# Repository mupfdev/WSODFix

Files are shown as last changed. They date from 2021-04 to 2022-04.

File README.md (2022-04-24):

# WSODFix

<p>
<a href="https://github.com/mupfelofen-de/WSODFix">
    
</a>
<a href="https://github.com/mupfelofen-de/WSODFix/blob/master/LICENSE.md">
    
</a>
<a href="https://www.travis-ci.com/mupfelofen-de/WSODFix">
    
</a>
</p>

## About

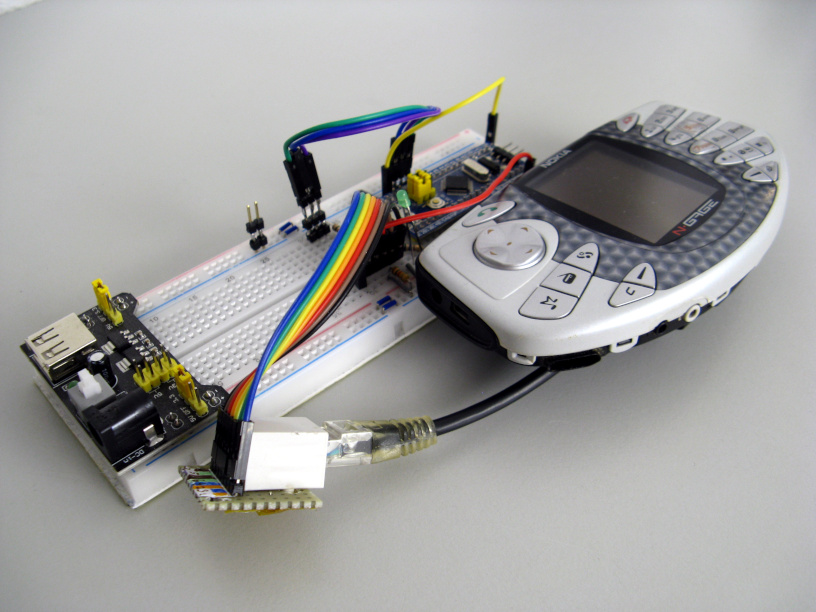
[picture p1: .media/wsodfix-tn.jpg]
WSODFix


Nokia mobile phones such as the N-Gage running early versions of the
Symbian OS suffer from a very common problem widely known as the White
Screen of Death or simply WSOD.  This happens when the internal memory
of the phone becomes so full that the unit can no longer boot and
becomes virtually unusable.

To solve this, the memory, referred to here as the user area, must be
formatted.

However, professional flashing equipment is needed to achieve this and
nowadays it is hard to find such equipment for sale.  More than often,
manufacturers, which cloned official service hardware, sold it in
addition to hardware licences in the form of a dongle.  Also, as new
devices would come out, old ones would literally be rendered unusable by
the manufacturers via the internet or sometimes by malware-infected
software released by competitors.

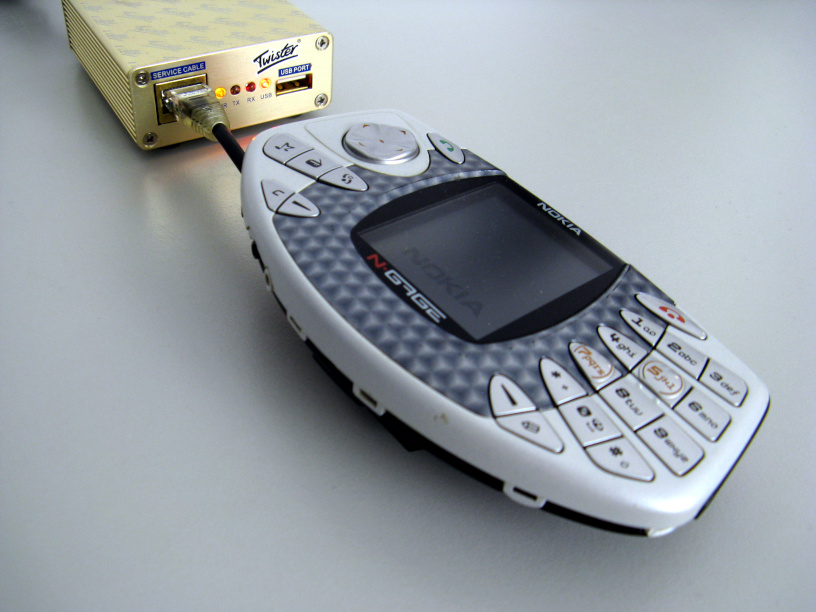
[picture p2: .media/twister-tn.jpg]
Twister


There is official software with which some of these devices can be
repaired and reactivated with, but access to reliable information is
anything but trivial.

This project is not an alternative to professional flashing equipment,
but aims at offering the possibility to make older Symbian phones
affected by a simple WSOD usable again by leveraging open-source
software and DIY hardware.

The project is based on a STM32F103C8 microcontroller board a.k.a. a
[blue pill board](http://reblag.dk/stm32/).

## Status

### Firmware

The firmware is 100% functional.

### Compatible phones

WSODFix has been tested with the following phones so far:

- Nokia N-Gage (NEM-4)
- Nokia N-Gage QD (RH-29)

## Operating instructions

Important: Never use WSODFix with a working phone! If the formatting
fails or is interrupted in the process, the device may no longer
boot. This can then only be repaired by a successful run.

1. Connect the UFS flashing cable to your phone.  It is very important
   to follow the correct insertion and removal procedure, otherwise the
   contact pins on the flash adapter will be damaged.  For the N-Gage
   and N-Gage QD, you must first press the adapter against the battery
   contacts and then down.

2. Attach the cable to the RJ45 connector of your WSODFix.

3. Connect the USB cable. Make sure that the USB port used can supply
   sufficient power for the phone and the microcontroller.

4. First, the LED should flash for about 20 seconds at a rate of 1
   second.  This is when the phone enters service mode.

5. Wait until the formatting process begins. The LED then flashes at a
   rate of 30ms.

6. The process is completed when the LED lights up continuously. You can
   then disconnect the phone and try to turn it on.  If the procedure
   fails, try again from the beginning.

## Hardware

### Parts needed

- UFS flashing cable or any way to connect the microcontroller to the
  corresponding pins on the phone (for example see the [N-Gage cable
  schematics](docs/Nokia_N-Gage_cable.pdf)),
- [STM32 blue pill board](http://reblag.dk/stm32/)
- RJ45 Ethernet jack,
- [RJ45 Breakout](https://www.sparkfun.com/products/716),
- 1× 1kΩ and 1× 10kΩ resistor (optional),
- 1× External status LED + dropping resistor (optional).

### Schematic

Note: The voltage divider is almost certainly optional.  Alternatively,
you can also set Vpp to 3V3.

Schematic

## FBus

The FBus is a bi-directional full-duplex serial type bus running at
115,200 bit/s, 8 data bits, no parity, one stop bit (8N1).

### Message structure

```text
  [      Header     ] [Payload] [xx xx]
  [1E xx xx xx xx xx] [Payload] [ CRC ]

  [ Header ]
  Byte 0 - F-Bus Frame ID
    E1 = Message via F-Bus cable
  Byte 1 - Destination address
  Byte 2 - Source address
    00 = Phone
    10 = Twister
  Byte 3 - Message type / command
    15 = Handshake/Auth ?
    7F = Acknowledge
    58 = Format user area
  Byte 4 - Payload size in bytes (MSB)
  Byte 5 - Payload size in bytes (LSB)

  [ Payload ]
  Byte 6 ... - Payload

  [ CRC ]
  Byte 1 - even checksum byte (all even bytes XORed together)
  Byte 2 - odd checksum byte  (all odd bytes XORed together)
```

### Formatting the user area

Here is a brief summary of the messages exchanged between the flashing
equipment and the Symbian phone when the user area is formatted.

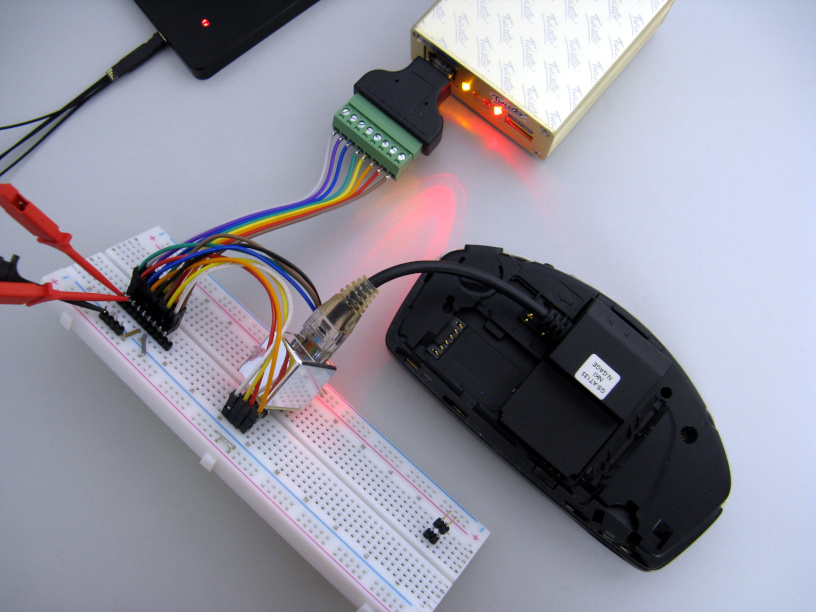
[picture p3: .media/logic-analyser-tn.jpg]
Logic analyser


This description is based on pure observation with the help of a logic
analyser.

```text
SEND 55 55 55 55 55 55 (synchronisation)

ca. 60ms pause

SEND [1E 00 10 15 00 08] [00 06 00 02 00 00 01 60]   [0F 79]
RECV [1E 10 00 7F 00 02] [15 00]                     [0B 6D]
RECV [1E 10 00 15 00 08] [06 27 00 65 05 05 01 (42)] [1C 08]
SEND [1E 00 10 7F 00 02] [15 (02)]                   [1B 7F]

ca. 16ms pause

SEND [1E 00 10 58 00 08] [00 0B 00 07 06 00 01 41]   [09 1D]
RECV [1E 10 00 7F 00 02] [58 01]                     [46 6C]

ca. 40-50s pause

RECV 55 55 (synchronisation)
RECV [1E 10 00 58 00 08] [0B 38 00 08 00 00 01 (43)] [14 33]

SEND [1E 00 10 7F 00 02] [58 (03)]                   [56 7E]
```

Surely you have noticed the parenthesised numbers.  These vary from run
to run.  The Symbian phone sends an initial value between 0x40 and 0x47.
The flashing equipment responds with this number minus 0x40.

Moreover, this number is apparently a kind of frame counter.  For
example, if the phone sends an initial 0x42, the next message sent from
the phone to the flasher will contain the number 0x43.  After 0x47,
there is an overflow back to 0x40.

This frame counter is implemented in WSODFix, but I do not know if it is
mandatory.  The rest of the payload data is completely ignored.  The
firmware only checks the message type of the received FBus messages.  In
my tests, this was 100% reliable.

Unfortunately FBus is a proprietary protocol developed by Nokia.  If you
have detailed specifications that you would like to share with me, I
would greatly appreciate it.  This would also help the further
development of this project.

## Installation

1. Install [PlatformIO Core](http://docs.platformio.org/page/core.html)
2. Run these commands:

```bash
    # Build project
    > platformio run

    # Upload firmware
    > platformio run --target upload

    # Clean build files (optional)
    > platformio run --target clean
```

## Licence

This project is licensed under the "The MIT License".  See the file
[LICENSE.md](LICENSE.md) for details.

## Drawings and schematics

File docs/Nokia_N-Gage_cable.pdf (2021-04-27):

### NOKIA NEM-4 ( N-GAGE ) from Dct4_UFS

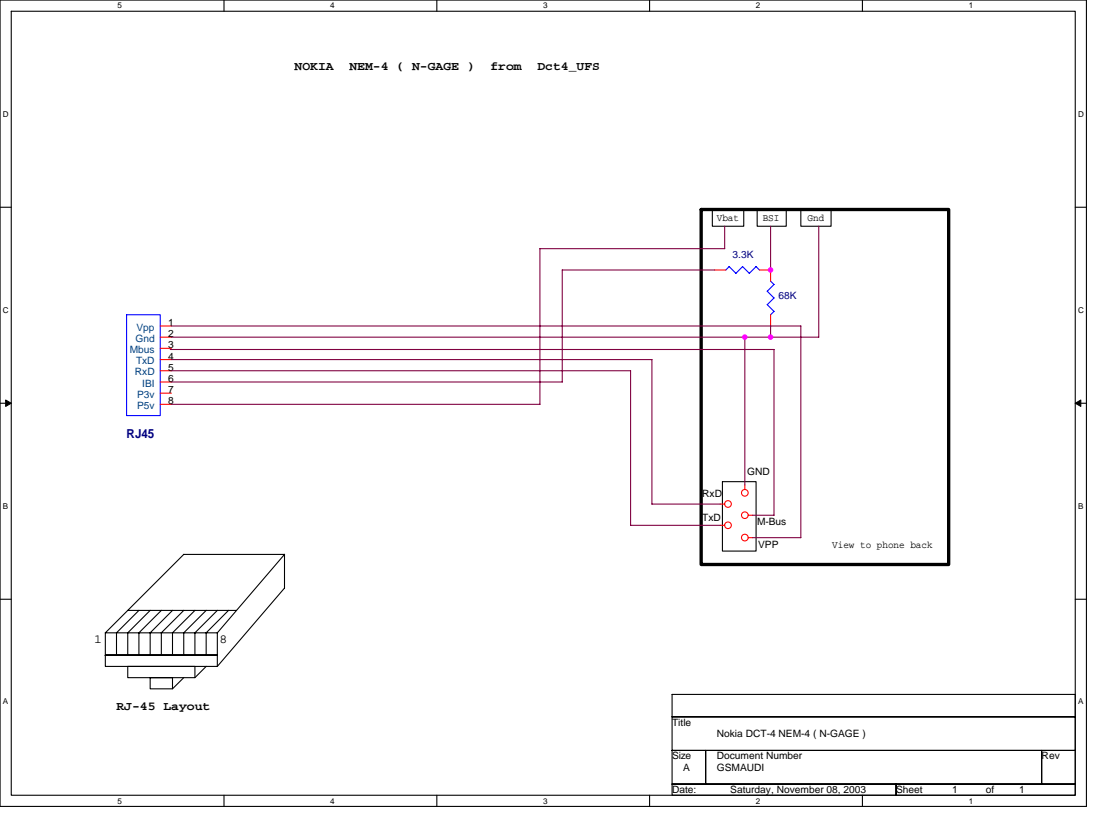
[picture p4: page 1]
Vbat; BSI; Gnd; RJ-45 Layout; Title; VPP; M-Bus TxD; GND; RxD; Vpp Gnd Mbus TxD RxD IBI P3v P5v

View to phone back

Nokia DCT-4 NEM-4 ( N-GAGE )

Size A | Document Number GSMAUDI | Rev

Date: Saturday, November 08, 2003 | Sheet 1 of 1

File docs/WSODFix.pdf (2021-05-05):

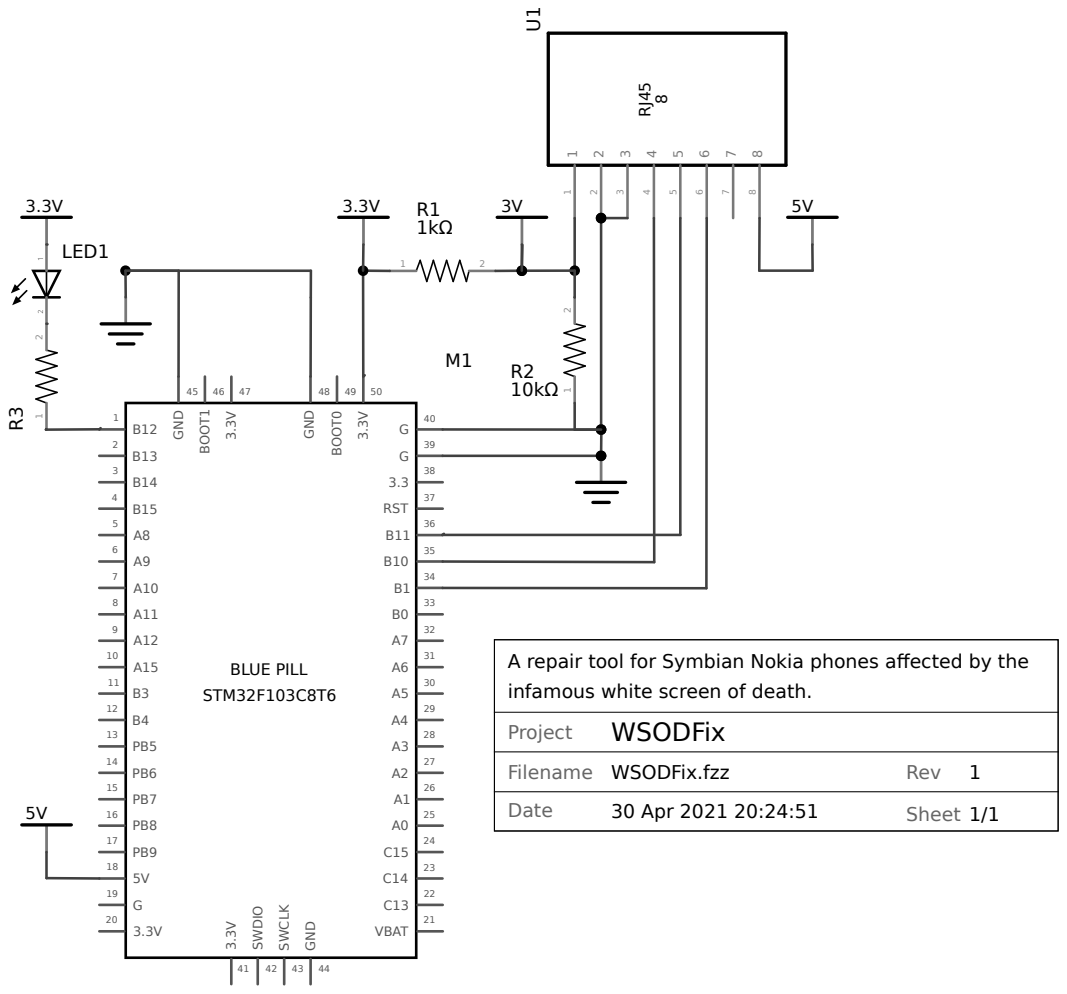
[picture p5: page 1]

A repair tool for Symbian Nokia phones affected by the
infamous white screen of death.

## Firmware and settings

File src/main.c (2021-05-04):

/* Spdx-License-Identifier: MIT */
/**
 * @file main.c
 * @brief WSODFix A repair tool for Symbian Nokia phones affected by the
 *        infamous white screen of death.
 */

#include <stdbool.h>
#include <stdint.h>
#include <string.h>

#include "stm32f1xx_hal.h"
#include "stm32f1xx_hal_tim.h"

#define BUF_SIZE     32
#define FBUS_MSG_LEN 16
#define FBUS_RX_ADDR 0x10
#define FBUS_TX_ADDR 0x00

typedef enum
{
    LED_IDLE               = 500,
    LED_ENTER_SERVICE_MODE = 1000,
    LED_FORMATTING         = 30,
    LED_ALL_DONE           = 0

} led_t;

UART_HandleTypeDef huart3;
TIM_HandleTypeDef  htim2;
TIM_HandleTypeDef  htim4;

static bool    all_done        = false;
static bool    initiate_format = false;
static uint8_t rx_byte         = 0;
static led_t   status_led      = LED_IDLE;
static uint8_t frame_counter   = 0;
static uint8_t tx_buffer[16]   = {
    0x55, 0x55, 0x55, 0x55, 0x55, 0x55,
    0x00, 0x06, 0x00, 0x02, 0x00, 0x00, 0x01, 0x60,
    0x0F, 0x79
};

static void system_init(void);
static void service_mode_init(void);
static void comm_init(void);
static void calculate_crc(uint8_t buffer[16], uint8_t* even_crc, uint8_t* odd_crc, bool append);
static void error_handler(void);

int main(void)
{
    system_init();
    service_mode_init();
    comm_init();

    while (1) {}
}

void HAL_UART_RxCpltCallback(UART_HandleTypeDef *huart)
{
    uint8_t fbus_message[FBUS_MSG_LEN] = { 0 };
    uint8_t fbus_header_index          = 0;
    bool    fbus_header_found          = false;

    static uint8_t ring_buffer[BUF_SIZE] = { 0 };
    static uint8_t ring_buffer_index     = 0;

    ring_buffer[ring_buffer_index] = rx_byte;

    for (uint8_t index = 0; index < BUF_SIZE; index += 1)
    {
        if (0x1E == ring_buffer[index])
        {
            fbus_header_index = index;
            fbus_header_found = true;
            break;
        }
    }

    if (true == fbus_header_found)
    {
        uint8_t payload_size  = 0;
        uint8_t even_crc      = 0;
        uint8_t odd_crc       = 0;
        uint8_t message_index = fbus_header_index;

        /* Extract FBus message */
        for (uint8_t index = 0; index < FBUS_MSG_LEN; index += 1)
        {
            fbus_message[index]  = ring_buffer[message_index];
            message_index       += 1;

            if (BUF_SIZE <= message_index)
            {
                message_index = 0;
            }
        }
        payload_size = fbus_message[5];

        /* Validate FBus message */
        if (0 == payload_size || payload_size > 8)
        {
            /* Invalid payload size */
        }
        else
        {
            calculate_crc(fbus_message, &even_crc, &odd_crc, false);

            if ((fbus_message[6 + payload_size] == even_crc) &&
                (fbus_message[7 + payload_size] == odd_crc))
            {
                /* Valid message found */
                /* Check if message is for us */
                if (FBUS_RX_ADDR == fbus_message[1])
                {
                    bool send_ack = true;
                    switch (fbus_message[3])
                    {
                        case 0x7F:
                            send_ack = false;
                            break;
                        case 0x58:
                            all_done = true;
                            break;
                        default:
                            frame_counter = fbus_message[5 + payload_size];
                            break;
                    }

                    if (true == send_ack)
                    {
                        uint8_t ack_buffer[10] = {
                            0x1E, FBUS_TX_ADDR, FBUS_RX_ADDR, 0x7F,
                            0x00, 0x02, fbus_message[3], frame_counter - 0x40
                        };
                        calculate_crc(ack_buffer, &even_crc, &odd_crc, true);
                        HAL_UART_Transmit_IT(&huart3, ack_buffer, 10);

                        if (0x15 == fbus_message[3])
                        {
                            initiate_format = true;
                        }
                    }
                }
                else
                {
                    /* Nothing to do here; message can be ignored */
                }

                /* Invalidate processed message */
                ring_buffer[fbus_header_index] = 0x00;
            }
        }
    }

    ring_buffer_index += 1;
    if (BUF_SIZE <= ring_buffer_index)
    {
        ring_buffer_index = 0;
    }
    HAL_UART_Receive_IT(&huart3, &rx_byte, 1);
}

void HAL_UART_TxCpltCallback(UART_HandleTypeDef *huart)
{
    /* Handshake acknowledge sent: initiate user area format */
    if (true == initiate_format)
    {
        tx_buffer[3]  = 0x58;
        tx_buffer[4]  = 0x00;
        tx_buffer[5]  = 0x08;
        tx_buffer[6]  = 0x00;
        tx_buffer[7]  = 0x0B;
        tx_buffer[8]  = 0x00;
        tx_buffer[9]  = 0x07;
        tx_buffer[10] = 0x06;
        tx_buffer[11] = 0x00;
        tx_buffer[12] = 0x01;
        tx_buffer[13] = 0x41;
        tx_buffer[14] = 0x09;
        tx_buffer[15] = 0x1D;

        status_led      = LED_FORMATTING;
        initiate_format = false;
        HAL_UART_Transmit_IT(&huart3, tx_buffer, 16);
    }
}

static void service_mode_init(void)
{
    led_t prev_pattern = status_led;

    status_led = LED_ENTER_SERVICE_MODE;

    HAL_Delay(10000);
    HAL_GPIO_WritePin(GPIOB, GPIO_PIN_1, GPIO_PIN_SET);
    HAL_Delay(987);
    HAL_GPIO_WritePin(GPIOB, GPIO_PIN_1, GPIO_PIN_RESET);
    HAL_Delay(849);
    HAL_GPIO_WritePin(GPIOB, GPIO_PIN_1, GPIO_PIN_SET);
    HAL_Delay(592);
    HAL_GPIO_WritePin(GPIOB, GPIO_PIN_1, GPIO_PIN_RESET);
    HAL_Delay(5000);

    status_led = prev_pattern;
}

static void comm_init(void)
{
    if (HAL_OK != HAL_UART_Transmit(&huart3, tx_buffer, 6, 100))
    {
        error_handler();
    }
    HAL_Delay(60);

    tx_buffer[0] = 0x1E;
    tx_buffer[1] = FBUS_TX_ADDR;
    tx_buffer[2] = FBUS_RX_ADDR;
    tx_buffer[3] = 0x15;
    tx_buffer[4] = 0x00;
    tx_buffer[5] = 0x08;
    if (HAL_OK != HAL_UART_Transmit(&huart3, tx_buffer, 16, 100))
    {
        error_handler();
    }

    HAL_UART_Receive_IT(&huart3, &rx_byte, 1);
}

static void calculate_crc(uint8_t buffer[16], uint8_t* even_crc, uint8_t* odd_crc, bool append)
{
    uint8_t payload_size = buffer[5];

    *even_crc = 0;
    *odd_crc  = 0;

    for (int i = 0; i < 6 + payload_size; i += 1)
    {
        if (i % 2 == 0)
        {
            *even_crc ^= buffer[i];
        }
        else
        {
            *odd_crc ^= buffer[i];
        }
    }

    if (true == append)
    {
        buffer[6 + payload_size] = *even_crc;
        buffer[7 + payload_size] = *odd_crc;
    }
}

static void system_init(void)
{
    RCC_OscInitTypeDef      RCC_OscInitStruct  = { 0 };
    RCC_ClkInitTypeDef      RCC_ClkInitStruct  = { 0 };
    GPIO_InitTypeDef        GPIO_InitStruct    = { 0 };
    TIM_ClockConfigTypeDef  sClockSourceConfig = { 0 };
    TIM_MasterConfigTypeDef sMasterConfig      = { 0 };

    /* Reset of all peripherals, Initialises the Flash interface and the
     * Systick.
     */
    HAL_Init();

    /* Initialises the RCC Oscillators according to the specified
     * parameters in the RCC_OscInitTypeDef structure.
     */
    RCC_OscInitStruct.OscillatorType = RCC_OSCILLATORTYPE_HSE;
    RCC_OscInitStruct.HSEState       = RCC_HSE_ON;
    RCC_OscInitStruct.HSEPredivValue = RCC_HSE_PREDIV_DIV1;
    RCC_OscInitStruct.HSIState       = RCC_HSI_ON;
    RCC_OscInitStruct.PLL.PLLState   = RCC_PLL_ON;
    RCC_OscInitStruct.PLL.PLLSource  = RCC_PLLSOURCE_HSE;
    RCC_OscInitStruct.PLL.PLLMUL     = RCC_PLL_MUL9;

    if (HAL_OK != HAL_RCC_OscConfig(&RCC_OscInitStruct))
    {
        error_handler();
    }

    /* Initialises the CPU, AHB and APB buses clocks */
    RCC_ClkInitStruct.ClockType      = RCC_CLOCKTYPE_HCLK | RCC_CLOCKTYPE_SYSCLK | RCC_CLOCKTYPE_PCLK1 | RCC_CLOCKTYPE_PCLK2;
    RCC_ClkInitStruct.SYSCLKSource   = RCC_SYSCLKSOURCE_PLLCLK;
    RCC_ClkInitStruct.AHBCLKDivider  = RCC_SYSCLK_DIV1;
    RCC_ClkInitStruct.APB1CLKDivider = RCC_HCLK_DIV2;
    RCC_ClkInitStruct.APB2CLKDivider = RCC_HCLK_DIV1;

    if (HAL_OK != HAL_RCC_ClockConfig(&RCC_ClkInitStruct, FLASH_LATENCY_2))
    {
        error_handler();
    }

    /* Enable GPIO port clocks */
    __HAL_RCC_GPIOC_CLK_ENABLE();
    __HAL_RCC_GPIOD_CLK_ENABLE();
    __HAL_RCC_GPIOB_CLK_ENABLE();

    /* Configure GPIO pin Output Level */
    HAL_GPIO_WritePin(GPIOC, GPIO_PIN_13, GPIO_PIN_SET);
    HAL_GPIO_WritePin(GPIOB, GPIO_PIN_12, GPIO_PIN_SET);
    HAL_GPIO_WritePin(GPIOB, GPIO_PIN_1,  GPIO_PIN_RESET);

    /* Configure GPIO pin : PC13 */
    GPIO_InitStruct.Pin   = GPIO_PIN_13;
    GPIO_InitStruct.Mode  = GPIO_MODE_OUTPUT_PP;
    GPIO_InitStruct.Pull  = GPIO_NOPULL;
    GPIO_InitStruct.Speed = GPIO_SPEED_FREQ_LOW;
    HAL_GPIO_Init(GPIOC, &GPIO_InitStruct);

    /* Configure GPIO pin : PB12 */
    GPIO_InitStruct.Pin   = GPIO_PIN_12;
    GPIO_InitStruct.Mode  = GPIO_MODE_OUTPUT_PP;
    GPIO_InitStruct.Pull  = GPIO_NOPULL;
    GPIO_InitStruct.Speed = GPIO_SPEED_FREQ_LOW;
    HAL_GPIO_Init(GPIOB, &GPIO_InitStruct);

    /* Configure GPIO pin : PB1 */
    GPIO_InitStruct.Pin   = GPIO_PIN_1;
    GPIO_InitStruct.Mode  = GPIO_MODE_OUTPUT_PP;
    GPIO_InitStruct.Pull  = GPIO_PULLDOWN;
    GPIO_InitStruct.Speed = GPIO_SPEED_FREQ_LOW;
    HAL_GPIO_Init(GPIOB, &GPIO_InitStruct);

    /* Initialise UART */
    huart3.Instance          = USART3;
    huart3.Init.BaudRate     = 115200;
    huart3.Init.WordLength   = UART_WORDLENGTH_8B;
    huart3.Init.StopBits     = UART_STOPBITS_1;
    huart3.Init.Parity       = UART_PARITY_NONE;
    huart3.Init.Mode         = UART_MODE_TX_RX;
    huart3.Init.HwFlowCtl    = UART_HWCONTROL_NONE;
    huart3.Init.OverSampling = UART_OVERSAMPLING_16;

    if (HAL_OK != HAL_UART_Init(&huart3))
    {
        error_handler();
    }

    htim2.Instance               = TIM2;
    htim2.Init.Prescaler         = 72-1;
    htim2.Init.CounterMode       = TIM_COUNTERMODE_UP;
    htim2.Init.Period            = 1000-1;
    htim2.Init.ClockDivision     = TIM_CLOCKDIVISION_DIV1;
    htim2.Init.RepetitionCounter = 0;
    htim2.Init.AutoReloadPreload = TIM_AUTORELOAD_PRELOAD_ENABLE;

    if (HAL_OK != HAL_TIM_Base_Init(&htim2))
    {
        error_handler();
    }

    sClockSourceConfig.ClockSource = TIM_CLOCKSOURCE_INTERNAL;

    if (HAL_OK != HAL_TIM_ConfigClockSource(&htim2, &sClockSourceConfig))
    {
        error_handler();
    }

    sMasterConfig.MasterOutputTrigger = TIM_TRGO_RESET;
    sMasterConfig.MasterSlaveMode     = TIM_MASTERSLAVEMODE_DISABLE;

    if (HAL_OK != HAL_TIMEx_MasterConfigSynchronization(&htim2, &sMasterConfig))
    {
        error_handler();
    }

    /* Start the TIM time Base generation in interrupt mode */
    if (HAL_OK != HAL_TIM_Base_Start_IT(&htim2))
    {
        error_handler();
    }
}

static void error_handler(void)
{
    HAL_GPIO_WritePin(GPIOC, GPIO_PIN_13, GPIO_PIN_SET);
    HAL_GPIO_WritePin(GPIOB, GPIO_PIN_12, GPIO_PIN_SET);
    __disable_irq();
    while (1) {}
}

void HAL_MspInit(void)
{
    __HAL_RCC_AFIO_CLK_ENABLE();
    __HAL_RCC_PWR_CLK_ENABLE();

    /* System interrupt init */
    /* DISABLE: JTAG-DP Disabled and SW-DP Disabled */
    __HAL_AFIO_REMAP_SWJ_DISABLE();
}

void HAL_UART_MspInit(UART_HandleTypeDef* huart)
{
    GPIO_InitTypeDef GPIO_InitStruct = { 0 };

    if (USART3 == huart->Instance)
    {
        /* Peripheral clock enable */
        __HAL_RCC_USART3_CLK_ENABLE();

        __HAL_RCC_GPIOB_CLK_ENABLE();
        /* USART3 GPIO Configuration
         *   PB10 --> USART3_TX
         *   PB11 --> USART3_RX
         */
        GPIO_InitStruct.Pin   = GPIO_PIN_10;
        GPIO_InitStruct.Mode  = GPIO_MODE_AF_PP;
        GPIO_InitStruct.Speed = GPIO_SPEED_FREQ_HIGH;
        HAL_GPIO_Init(GPIOB, &GPIO_InitStruct);

        GPIO_InitStruct.Pin  = GPIO_PIN_11;
        GPIO_InitStruct.Mode = GPIO_MODE_INPUT;
        GPIO_InitStruct.Pull = GPIO_NOPULL;
        HAL_GPIO_Init(GPIOB, &GPIO_InitStruct);

        /* USART3 interrupt Init */
        HAL_NVIC_SetPriority(USART3_IRQn, 1, 0);
        HAL_NVIC_EnableIRQ(USART3_IRQn);
    }
}

void HAL_UART_MspDeInit(UART_HandleTypeDef* huart)
{
    if (USART3 == huart->Instance)
    {
        /* Peripheral clock disable */
        __HAL_RCC_USART3_CLK_DISABLE();

        /* USART3 GPIO Configuration
         *   PB10 --> USART3_TX
         *   PB11 --> USART3_RX
         */
        HAL_GPIO_DeInit(GPIOB, GPIO_PIN_10 | GPIO_PIN_11);

        /* USART3 interrupt DeInit */
        HAL_NVIC_DisableIRQ(USART3_IRQn);
    }
}

void HAL_TIM_Base_MspInit(TIM_HandleTypeDef* htim_base)
{
    if (TIM2 == htim_base->Instance)
    {
        /* Peripheral clock enable */
        __HAL_RCC_TIM2_CLK_ENABLE();

        /* TIM2 interrupt Init */
        HAL_NVIC_SetPriority(TIM2_IRQn, 2, 0);
        HAL_NVIC_EnableIRQ(TIM2_IRQn);
    }
}

void HAL_TIM_Base_MspDeInit(TIM_HandleTypeDef* htim_base)
{
    if (TIM2 == htim_base->Instance)
    {
        /* Peripheral clock disable */
        __HAL_RCC_TIM2_CLK_DISABLE();

        /* TIM2 interrupt DeInit */
        HAL_NVIC_DisableIRQ(TIM2_IRQn);
    }
}

void HAL_TIM_PeriodElapsedCallback(TIM_HandleTypeDef *htim)
{
    if (TIM2 == htim->Instance)
    {
        if (true == all_done)
        {
            HAL_GPIO_WritePin(GPIOC, GPIO_PIN_13, GPIO_PIN_RESET);
            HAL_GPIO_WritePin(GPIOB, GPIO_PIN_12, GPIO_PIN_RESET);
        }
        else
        {
            static uint32_t ms_count = 0;
            ms_count += 1;
            if (ms_count >= (uint32_t)status_led)
            {
                HAL_GPIO_TogglePin(GPIOC, GPIO_PIN_13);
                HAL_GPIO_TogglePin(GPIOB, GPIO_PIN_12);
                ms_count = 0;
            }
        }
    }

    if (TIM4 == htim->Instance)
    {
        HAL_IncTick();
    }
}

HAL_StatusTypeDef HAL_InitTick(uint32_t TickPriority)
{
    RCC_ClkInitTypeDef clkconfig;
    uint32_t           uwTimclock       = 0;
    uint32_t           uwPrescalerValue = 0;
    uint32_t           pFLatency;

    /* Configure the TIM4 IRQ priority */
    HAL_NVIC_SetPriority(TIM4_IRQn, TickPriority, 0);

    /* Enable the TIM4 global Interrupt */
    HAL_NVIC_EnableIRQ(TIM4_IRQn);
    /* Enable TIM4 clock */
    __HAL_RCC_TIM4_CLK_ENABLE();

    /* Get clock configuration */
    HAL_RCC_GetClockConfig(&clkconfig, &pFLatency);

    /* Compute TIM4 clock */
    uwTimclock = 2*HAL_RCC_GetPCLK1Freq();
    /* Compute the prescaler value to have TIM4 counter clock equal to
     * 1MHz
     */
    uwPrescalerValue = (uint32_t) ((uwTimclock / 1000000U) - 1U);

    /* Initialize TIM4 */
    htim4.Instance = TIM4;

    /* Initialize TIMx peripheral as follow:
     * + Period = [(TIM4CLK/1000) - 1]. to have a (1/1000) s time base.
     * + Prescaler = (uwTimclock/1000000 - 1) to have a 1MHz counter clock.
     * + ClockDivision = 0
     * + Counter direction = Up
     */
    htim4.Init.Period        = (1000000U / 1000U) - 1U;
    htim4.Init.Prescaler     = uwPrescalerValue;
    htim4.Init.ClockDivision = 0;
    htim4.Init.CounterMode   = TIM_COUNTERMODE_UP;

    if (HAL_OK == HAL_TIM_Base_Init(&htim4))
    {
        /* Start the TIM time Base generation in interrupt mode */
        return HAL_TIM_Base_Start_IT(&htim4);
    }

    /* Return function status */
    return HAL_ERROR;
}

void HAL_SuspendTick(void)
{
    /* Disable TIM4 update Interrupt */
    __HAL_TIM_DISABLE_IT(&htim4, TIM_IT_UPDATE);
}

void HAL_ResumeTick(void)
{
    /* Enable TIM4 Update interrupt */
    __HAL_TIM_ENABLE_IT(&htim4, TIM_IT_UPDATE);
}

/* Cortex-M3 Processor Interruption and Exception Handlers */

/*
 * STM32F1xx Peripheral Interrupt Handlers
 * Add here the Interrupt Handlers for the used peripherals.
 * For the available peripheral interrupt handler names,
 * please refer to the startup file (startup_stm32f1xx.s).
 */
void TIM2_IRQHandler(void)
{
    HAL_TIM_IRQHandler(&htim2);
}

void TIM4_IRQHandler(void)
{
    HAL_TIM_IRQHandler(&htim4);
}

void USART3_IRQHandler(void)
{
    HAL_UART_IRQHandler(&huart3);
}

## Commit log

2021-04-23 Update overall UART handling, set LED according to current app status e.g. to indicate errors
    [main.c]
2021-04-24 Add DSLogic example trace
2021-04-27 Add DSLogic WSODFix trace
2021-04-27 Update LED handling (blocking -> non-blocking), add service mode initialisation routine
2021-04-27 Add N-Gage cable schematic
2021-04-27 Add wiring diagram
2021-04-27 Wiring diagram, cosmetic changes
2021-04-27 Add image of prototype
2021-04-27 Update list of compatible devices
2021-04-29 Update status LED handling, update README.md, overall cleanup
2021-04-30 Will fix and close #1, rewrite entire firmware to handle FBus messages dynamically
    [main.c]
2021-04-30 Add Fritzing project file
    [WSODFix.fzz]
2021-04-30 Add schematic
2021-05-02 Update file header, fix indentation
    [main.c]
2021-05-05 Add schematic as PDF

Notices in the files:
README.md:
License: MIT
